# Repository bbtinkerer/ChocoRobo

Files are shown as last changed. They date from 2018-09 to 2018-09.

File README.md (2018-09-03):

# ChocoRobo - Autonomous Chocolate Delivery Robot

By bbtinkerer (<http://bb-tinkerer.blogspot.com/>)

## Description

Simple and easy to build face following robot with off the shelf parts for anyone to build. For use on Adafruit's Circuit Playground Express (CPX) and Crickit. ChocoRobo is connected to a Google AIY Vision that sends data serially. Google AIY Vision sends the mid X coordinate of the detected face along with the size of the bounding box around the face. This code then adjust the left and right motor speeds to movet he robot towards the direction of the face. Also, the NeoPixels on the CPX light up in the direction of the face.

Project documention on [hackster.io](https://www.hackster.io/bbtinkerer/chocorobo-autonomous-chocolate-delivery-robot-597fd0).

YouTube Videos

* [ChocoRobo - Autonomous Chocolate Delivery Robot](https://youtu.be/YWtPi1448u0)
* [ChocoRobo - Autonomous Chocolate Delivery Robot Info](https://youtu.be/wd7FyPMLFyc)
* [ChocoRobo - Autonomous Chocolate Delivery Robot Build](https://youtu.be/Vt1zGyjBj6I)

## Requirements

* [Circuit Playground Express](https://learn.adafruit.com/adafruit-circuit-playground-express?view=all) - Follow instructions on setup, the code requires CircuitPython v3.
* [Adafruit CRICKIT for Circuit Playground Express](https://learn.adafruit.com/adafruit-crickit-creative-robotic-interactive-construction-kit?view=all)
* [Google AIY  Vision Kit](https://aiyprojects.withgoogle.com/vision/) - Used image aiyprojects-2018-08-03.img, the image on the included SD card was too old and didn't include the video streaming server.

## Installation

### Circuit Playground Express

Follow the instructions at Adafruit to copy the code.py from the CPX directory to the Circuit Playground Express.

### Google AIY Vision Kit

Need to enable UART on the Raspberry Pi (reference: [The Raspberry Pi UARTs](https://www.raspberrypi.org/documentation/configuration/uart.md)).

First disable Linux's use of console UART. Enter the following at the console:

```
$ sudo raspi-config
```

1. Choose option 5.
2. Choose P6 Serial.
3. Would you like a login shell to be accessible over serial? Choose No.
4. Would you like the serial port hardware to be enabled? Choose Yes.
5. Confirm The serial login shell is disabled. The serial interface is enabled. Choose Ok.
6. Choose Finish.
7. Would you like to reboot now? Choose No.

Make a copy of /boot/config.txt. Enter the following at the console (I like vim, use whatever text editor you like):

```
$ cd /boot
$ sudo cp config.txt config.bak.txt
$ sudo vim config.txt
```

Append the following to the bottom of config.txt:

```
# Disable the Bluetooth device and restores UART0/ttyAMA0 to GPIOs 14 and 15.
dtoverlay=pi3-disable-bt
```

Disable the system service that initialises the modem so it doesn't use the UART.

```
$ sudo systemctl disable hciuart
```

Should see response of:

```
Removed /etc/systemd/system/multi-user.target.wants/hciuart.service.
```

Replace the joy_detection_demo.py located in the ~/AIY-projects-python/src/examples/vision/joy/ directory of the Vision Kit with the joy_detection_demo.py from the RaspberryPi directory from this repo.

Reboot.

```
$ sudo shutdown -r now
```

## Configuration

There are some settings towards the top of code.py that will need adjustments depending on your hardware and your desired behavior of the robot. The following settings will most likely need tweaking:

* **MAX_DATA_IN_TIME_MARGIN** - Time in seconds to allow FaceBot to keep moving after the last time received data. Lower if overturning, but too low makes for a twitchy robot.
* **MOTOR_BASE_SPEED_RIGHT/MOTOR_BASE_SPEED_LEFT** - Base speeds for the motors. Not all motors are the same so may need to tweak where they rotate at the same starting speed.
* **MOTOR_RIGHT_ERROR_CORRECTION/MOTOR_LEFT_ERROR_CORRECTION** - I had to put in some correction for the motor speeds, I just guessed and trial and error till looked right. The left motor was slower than the right so needed more speed and vice versa for the right motor.
* **Kp/Kd** - Constants to do proportional and derivative control of movement, you may need to tweak to get your bot to move smoothly.
* **MAX_FACE_WIDTH** - Stops the robot from moving when the face exceeds this width so the bot doesn't run into the person.

## Known Issues

If you discover any bugs, feel free to create an issue on GitHub fork and
send a pull request.

## Authors

* bbtinkerer (https://github.com/bbtinkerer/)

## Contributing

1. Fork it
2. Create your feature branch (`git checkout -b my-new-feature`)
3. Commit your changes (`git commit -am 'Add some feature'`)
4. Push to the branch (`git push origin my-new-feature`)
5. Create new Pull Request

## License

This program is free software: you can redistribute it and/or modify it under the terms of the GNU General Public License as published by the Free Software Foundation, either version 3 of the License, or (at your option) any later version.

This program is distributed in the hope that it will be useful, but WITHOUT ANY WARRANTY; without even the implied warranty of MERCHANTABILITY or FITNESS FOR A PARTICULAR PURPOSE.  See the GNU General Public License for more details.

You should have received a copy of the GNU General Public License along with this program.  If not, see <http://www.gnu.org/licenses/>.

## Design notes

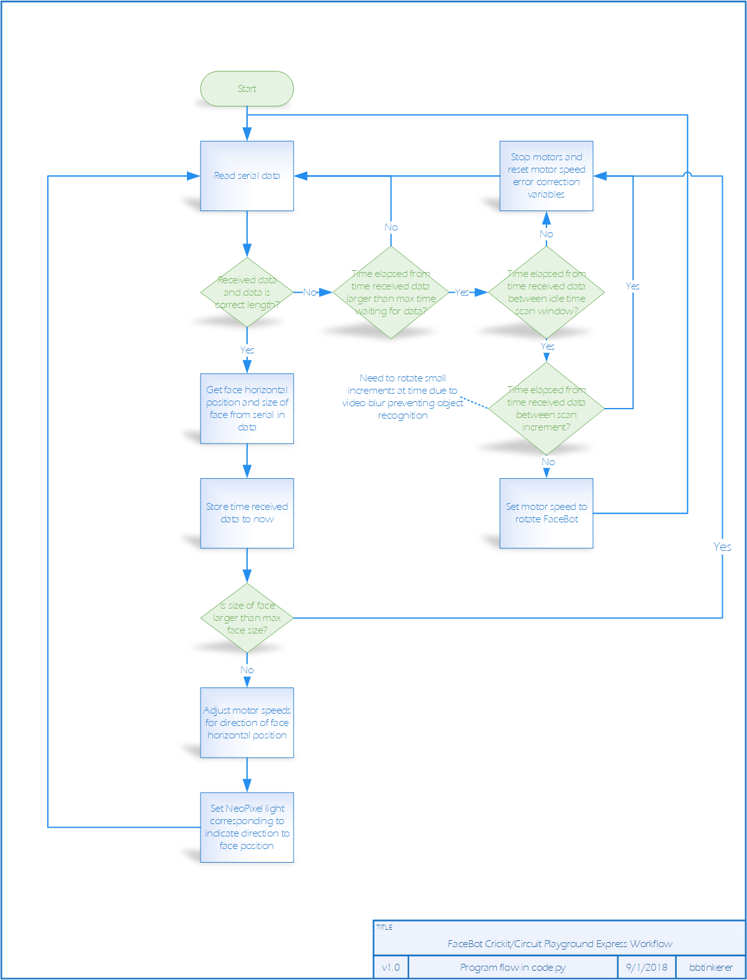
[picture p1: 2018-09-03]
Visio/FaceBotWf.png

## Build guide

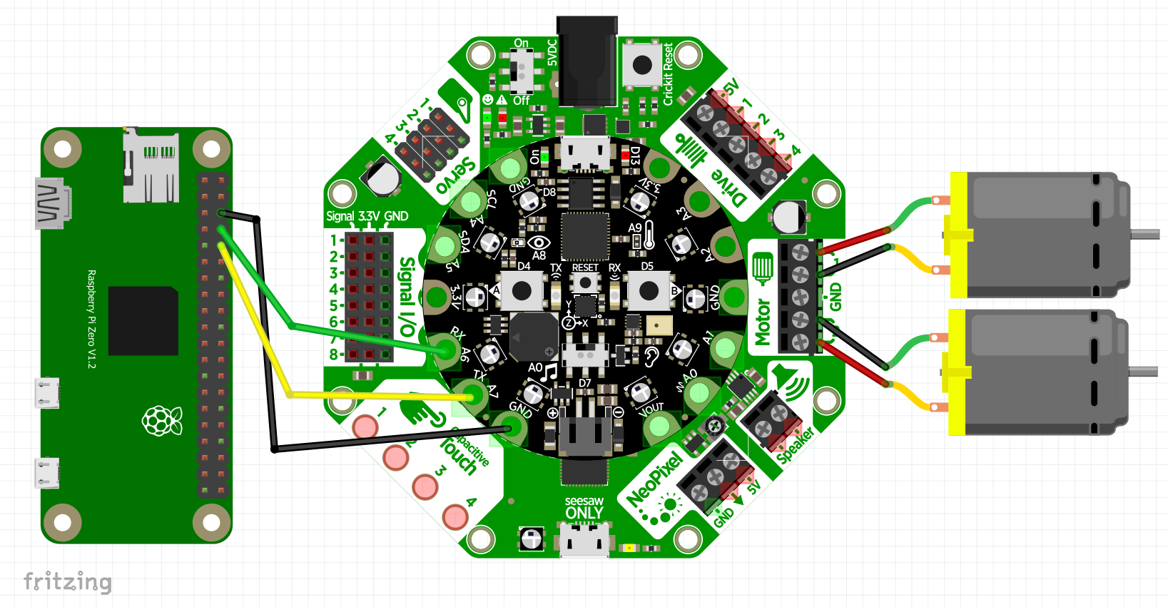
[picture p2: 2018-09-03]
fritzing/FaceBotWiring.png

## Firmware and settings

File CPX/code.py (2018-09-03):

# Copyright (c) 2018 bbtinkerer
#
# Simple and easy to build face following robot with off the shelf parts 
# for anyone to build. For use on Adafruit's Circuit Playground 
# Express (CPX) and Crickit. ChocoRobo is connected to a Google AIY Vision
# that sends data serially. Google AIY Vision sends the mid X coordinate
# of the detected face along with the size of the bounding box around the
# face. This code then adjust the left and right motor speeds to move
# the robot towards the direction of the face. Also, the NeoPixels on the
# CPX light up in the direction of the face.
#
# Licensed under the Apache License, Version 2.0 (the "License");
# you may not use this file except in compliance with the License.
# You may obtain a copy of the License at
#
#     http://www.apache.org/licenses/LICENSE-2.0
#
# Unless required by applicable law or agreed to in writing, software
# distributed under the License is distributed on an "AS IS" BASIS,
# WITHOUT WARRANTIES OR CONDITIONS OF ANY KIND, either express or implied.
# See the License for the specific language governing permissions and
# limitations under the License.
# 
""" ChocoRobo - Autonomous Chocolate Delivery Robot """
import board
import busio
import time
import ure
from adafruit_crickit import crickit
from adafruit_circuitplayground.express import cpx

# Settings for the NeoPixels
PIXEL_DIRECTION_COLOR = (0, 0x10, 0)  #green
PIXEL_OFF_COLOR = (0, 0, 0)  #black
PIXEL_BRIGHTNESS = 0.2
PIXEL_DEFAULT_DIRECTION_INDEX = 2

# Time in seconds to allow FaceBot to keep moving after the last time received data
# Lower if overturning, but too low makes for a twitchy robot
MAX_DATA_IN_TIME_MARGIN = 0.18

# Time in seconds to start scanning around for faces when no data received
IDLE_TIME_SCAN_START = 10
IDLE_TIME_SCAN_END = 30
# Cannot continously rotate due to video being blurry and the Google AIY Vision not able to pick up faces.
# Only rotating a small amount of time then pausing. Pause up to start time, then rotates till end time.
SCAN_INCREMENT_START_TIME = 1.3
SCAN_INCREMENT_END_TIME = 1.5

# Base speeds for the motors. Not all motors are the same so may need to tweak where they rotate at the same starting speed.
MOTOR_BASE_SPEED_RIGHT = 0.5
MOTOR_BASE_SPEED_LEFT = 0.425

# I had to put in some correction for the motor speeds, I just guessed and trial and error till looked right.
# The left motor was slower than the right so needed more speed and vice versa for the right motor.
MOTOR_RIGHT_ERROR_CORRECTION = 1.05
MOTOR_LEFT_ERROR_CORRECTION = 0.90

# Constants to do proportional and derivative control of movement, you may need to tweak to get your bot to move smoothly.
Kp = 0.0003
Kd = 0.0005

# The center position. Google AIY Vision takes 1640 wide video.
CENTER_FACE_POSITION = 820

# Stops the robot from moving when the face exceeds this width so the bot doesn't run into the person.
MAX_FACE_WIDTH = 650

# For the proportional and derivative control of movement
errorCurrent = 0
errorLast = 0
motorSpeed = 0

# Initialze serial communication.
uart = busio.UART(board.TX, board.RX, baudrate=115200, timeout=10)

# Initialize the NeoPixels.
pixels = cpx.pixels
pixels.auto_write = False
pixels.brightness = PIXEL_BRIGHTNESS
currentPixelDirection = PIXEL_DEFAULT_DIRECTION_INDEX

# Initalize for the motors.
leftMotor = crickit.dc_motor_1
rightMotor = crickit.dc_motor_2
leftMotorSpeed = 0
rightMotorSpeed = 0

# Regular expression to help extract the data from the serial communication.
re = ure.compile('\D')

# And the last of initialization of variables.
lastDataTime = 0
elapsedTime = 0
facePosition = CENTER_FACE_POSITION
faceWidth = 0

def showPixelDirection(facePosition):
    """
    Lights the corresponding NeoPixel that points in the direction of of the parameter facePosition.
    """
    global currentPixelDirection
    pixels[currentPixelDirection] = PIXEL_OFF_COLOR
    
    if facePosition <= 328:
        currentPixelDirection = 4
    elif facePosition <= 656:
        currentPixelDirection = 3
    elif facePosition <= 984:
        currentPixelDirection = 2
    elif facePosition <= 1312:
        currentPixelDirection = 1
    else:
        currentPixelDirection = 0
        
    pixels[currentPixelDirection] = PIXEL_DIRECTION_COLOR
    pixels.show()

def boundMotorSpeed(speed):
    """
    Bound speed to the limits allowed by crickit motor.throttle
    """
    if speed < -1:
        return -1
    if speed > 1:
        return 1
    return speed

def resetMotorSpeeds():
    """
    Stop the motors.
    """
    leftMotor.throttle = 0
    rightMotor.throttle = 0
    errorCurrent = 0
    errorLast = 0

showPixelDirection(currentPixelDirection)

while True:
    data = uart.read(9)
    if data is not None and len(data) == 9:  # Data was received
        #print(data) # should be in form b'NNNN,NNNN' where NNNN is a leading zero padded 4 digit number, first NNNN is horizontal position of face, second NNNN is width of face
        data = re.split(str(data))  # splits to ['', '', 'NNNN', 'NNNN']
        facePosition = int(data[2])  
        faceWidth = int(data[3])
        lastDataTime = time.monotonic()
        #print("serial facePosition: {0}, faceWidth: {1}, lastDataTime: {2}".format(facePosition, faceWidth, lastDataTime))

    elapsedTime = time.monotonic() - lastDataTime
    #print('elapsedTime', elapsedTime)
    
    if IDLE_TIME_SCAN_START < elapsedTime % IDLE_TIME_SCAN_END and SCAN_INCREMENT_START_TIME < elapsedTime % SCAN_INCREMENT_END_TIME:
        # Have to only rotate the bot a little a time because the video is blurry during rotation and the Google AIY Vision
        # will not recognize a face
        leftMotor.throttle = MOTOR_BASE_SPEED_LEFT
        rightMotor.throttle = -MOTOR_BASE_SPEED_RIGHT
    elif elapsedTime > MAX_DATA_IN_TIME_MARGIN or faceWidth > MAX_FACE_WIDTH:
        resetMotorSpeeds()
    else:
        # Yay, we got face data. Compute the PD motor speeds to get the bot to the person smoothly.
        errorCurrent = CENTER_FACE_POSITION - facePosition
        motorSpeed = Kp * errorCurrent + Kd * (errorCurrent - errorLast)
        errorLast = errorCurrent
        
        leftMotorSpeed = MOTOR_BASE_SPEED_LEFT - (motorSpeed * MOTOR_LEFT_ERROR_CORRECTION)
        rightMotorSpeed = MOTOR_BASE_SPEED_RIGHT + (motorSpeed * MOTOR_RIGHT_ERROR_CORRECTION)
        
        leftMotor.throttle = boundMotorSpeed(leftMotorSpeed)
        rightMotor.throttle = boundMotorSpeed(rightMotorSpeed)
        print('left: {0}, right: {1}'.format(leftMotor.throttle, rightMotor.throttle))
        
    showPixelDirection(facePosition)

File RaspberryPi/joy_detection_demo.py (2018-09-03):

#!/usr/bin/env python3
# Copyright 2017 Google Inc.
#
# Licensed under the Apache License, Version 2.0 (the "License");
# you may not use this file except in compliance with the License.
# You may obtain a copy of the License at
#
#     http://www.apache.org/licenses/LICENSE-2.0
#
# Unless required by applicable law or agreed to in writing, software
# distributed under the License is distributed on an "AS IS" BASIS,
# WITHOUT WARRANTIES OR CONDITIONS OF ANY KIND, either express or implied.
# See the License for the specific language governing permissions and
# limitations under the License.
# 
# Modified by bbtinkerer September, 2018.  Added serial communication to 
# send the position and width of the first face recognized.
# Original file from https://github.com/google/aiyprojects-raspbian 
# commit 93a6306 on August 3, 2018.
"""Joy detection demo."""
import argparse
import collections
import contextlib
import io
import logging
import math
import os
import queue
import serial  # serial communication for ChocoRobo
import signal
import sys
import threading
import time

from aiy.leds import Leds
from aiy.leds import Pattern
from aiy.leds import PrivacyLed
from aiy.toneplayer import TonePlayer
from aiy.vision.inference import CameraInference
from aiy.vision.models import face_detection
from aiy.vision.streaming.server import StreamingServer, InferenceData

from gpiozero import Button
from picamera import PiCamera

from PIL import Image
from PIL import ImageDraw
from PIL import ImageFont

logging.basicConfig(level=logging.INFO)
logger = logging.getLogger(__name__)

RED_COLOR = (255, 0, 0)

JOY_COLOR = (255, 70, 0)
SAD_COLOR = (0, 0, 64)

JOY_SCORE_PEAK = 0.85
JOY_SCORE_MIN = 0.10

JOY_SOUND = ('C5q', 'E5q', 'C6q')
SAD_SOUND = ('C6q', 'E5q', 'C5q')
MODEL_LOAD_SOUND = ('C6w', 'c6w', 'C6w')
BEEP_SOUND = ('E6q', 'C6q')

FONT_FILE = '/usr/share/fonts/truetype/freefont/FreeSans.ttf'

BUZZER_GPIO = 22
BUTTON_GPIO = 23

@contextlib.contextmanager
def stopwatch(message):
    try:
        logger.info('%s...', message)
        begin = time.time()
        yield
    finally:
        end = time.time()
        logger.info('%s done. (%fs)', message, end - begin)


def blend(color_a, color_b, alpha):
    return tuple([math.ceil(alpha * color_a[i] + (1.0 - alpha) * color_b[i]) for i in range(3)])


def average_joy_score(faces):
    if faces:
        return sum(face.joy_score for face in faces) / len(faces)
    return 0.0


def draw_rectangle(draw, x0, y0, x1, y1, border, fill=None, outline=None):
    assert border % 2 == 1
    for i in range(-border // 2, border // 2 + 1):
        draw.rectangle((x0 + i, y0 + i, x1 - i, y1 - i), fill=fill, outline=outline)


def normalize_bounding_box(bounding_box, width, height):
    x, y, w, h = bounding_box
    return (x / width, y / height, w / width, h / height)


def server_inference_data(width, height, faces, joy_score):
    data = InferenceData()
    for face in faces:
        x, y, w, h = normalize_bounding_box(face.bounding_box, width, height)
        color = blend(JOY_COLOR, SAD_COLOR, face.joy_score)
        data.add_rectangle(x, y, w, h, color, round(face.joy_score * 10))
        data.add_label("%.2f" % face.joy_score, x, y, color, 1)
    data.add_label('Faces: %d Avg. score: %.2f' % (len(faces), joy_score),
                   0, 0, blend(JOY_COLOR, SAD_COLOR, joy_score), 2)
    return data


class AtomicValue:

    def __init__(self, value):
        self._lock = threading.Lock()
        self._value = value

    @property
    def value(self):
        with self._lock:
            return self._value

    @value.setter
    def value(self, value):
        with self._lock:
            self._value = value


class MovingAverage:

    def __init__(self, size):
        self._window = collections.deque(maxlen=size)

    def next(self, value):
        self._window.append(value)
        return sum(self._window) / len(self._window)


class Service:

    def __init__(self):
        self._requests = queue.Queue()
        self._thread = threading.Thread(target=self._run, daemon=True)
        self._thread.start()

    def _run(self):
        while True:
            request = self._requests.get()
            if request is None:
                break
            self.process(request)
            self._requests.task_done()

    def process(self, request):
        pass

    def submit(self, request):
        self._requests.put(request)

    def close(self):
        self._requests.put(None)
        self._thread.join()

    def __enter__(self):
        return self

    def __exit__(self, exc_type, exc_value, exc_tb):
        self.close()


class Player(Service):
    """Controls buzzer."""

    def __init__(self, gpio, bpm):
        super().__init__()
        self._toneplayer = TonePlayer(gpio, bpm)

    def process(self, sound):
        self._toneplayer.play(*sound)

    def play(self, sound):
        self.submit(sound)
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
